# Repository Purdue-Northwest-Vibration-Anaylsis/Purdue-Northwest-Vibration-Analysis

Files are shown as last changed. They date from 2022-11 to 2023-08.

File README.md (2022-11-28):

# Purdue-Northwest-Vibration-Analysis
Vibration analysis senior design project for Purdue Northwest.

# Background
Household appliances breaking down is a costly issue for everyday consumers. 
There are typically two options when an appliance breaks down: reactive maintenance or buying a replacement, both of which are extremely costly. Proactive maintenance, as opposed to reactive maintenance, is identifying and fixing the issue before it results in a breakdown. Industries, such as the steel industry for example, have been investing in monitoring equipment on their machinery to identify and fix issues before they cause a total breakdown. Individual consumers do not yet have this luxury, so oftentimes their appliances completely break before they are aware of an issue.

# Objective
The open vibration analysis project seeks to prevent reactive maintenance of consumer appliances and instead allow the owners to perform proactive maintenance. Reactive maintenance, which is fixing the problem after it breaks down, is almost always more costly and time consuming than proactive maintenance, which is fixing a problem before it results in a complete breakdown. The objective of this project is to build a device that would be able to identify the problem before it results in a breakdown and alert the consumer to fix it. This would save the consumer money and reduce downtime. 

# Approach
The vibration analysis device would work by being attached to the consumer appliance.  It would use a combination of an accelerometer, to measure vibration, and a contact microphone, to measure sound. These measurements would be analyzed in a custom software that will be able to recognize any abnormalities in vibration or sound. That way, if the appliance begins to show signs of an imminent breakdown, the device will alert the user.

# Outcome
The anticipated outcome is a relatively small device, around 5”x5”, that can easily be attached to a consumer appliance, connected to a power supply, and easily configured with a user-friendly software. This software could connect to a phone and send notification alerts when the device senses abnormalities in the appliance. The device would ideally serve a wide range of consumers and work with most home appliances, such as washing/drying machines, refrigerators, AC units, and more.

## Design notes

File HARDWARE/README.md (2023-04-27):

# HARDWARE 
Sensors:

Accelerometer: ADXL345    
    
Microphone: SPH0645

Microprocessor/Bluetooth and WiFi Module:  ESP32-WROOM-32D

USB Bridge controller: CP2102 USB to UART

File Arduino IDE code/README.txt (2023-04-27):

These programs will allow you to test the functionality of the board, currently we have separate programs to test the components individually. 
In the future we will create programs that can test both components and perform computations such as FFT and filtering.

For the accelerometer testing code, you will need to install a few libraries on Arduino IDE.
First, you need to install the "Adafruit Unifier Sensor" library by Adafruit.
Next, install the "Adafruit ADXL345" library by Adafruit.
The ESP32 board can be on any version in the boards manager tab.
These are all you will need to test the accelerometer, but for more information consult this article: https://www.techcoil.com/blog/how-to-use-a-esp32-development-board-to-read-from-an-adxl345-accelerometer/

For the microphone testing code, you do not need to install any libraries.
The ESP32 board needs to be on version 1.0.3 in the boards manager tab for the code to work. 
This program has very basic filtering, but it still needs a lot of work.
This article contains more information: https://diyi0t.com/i2s-sound-tutorial-for-esp32/

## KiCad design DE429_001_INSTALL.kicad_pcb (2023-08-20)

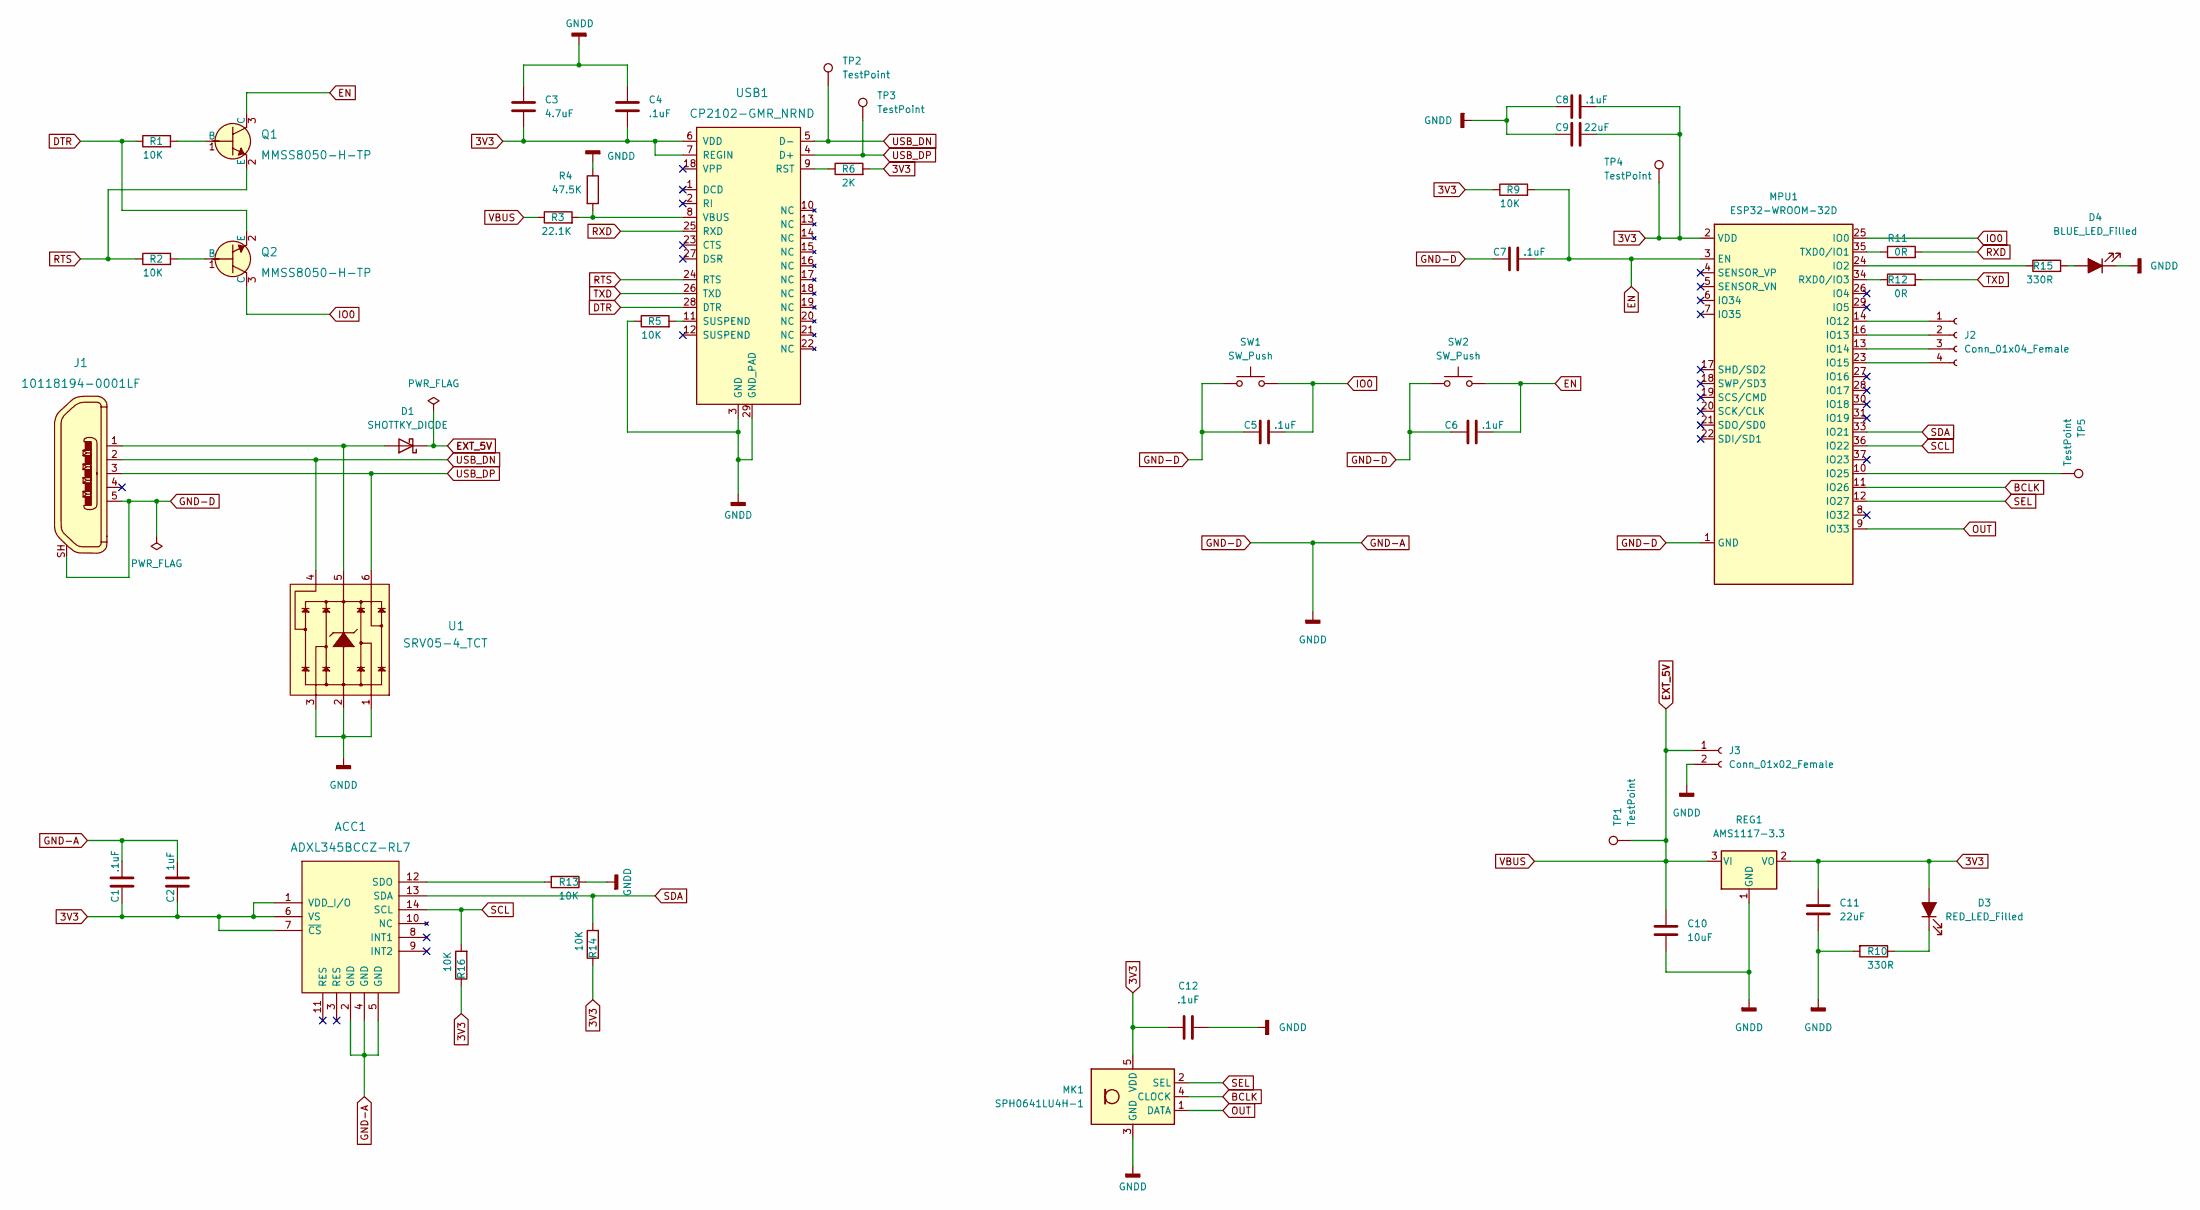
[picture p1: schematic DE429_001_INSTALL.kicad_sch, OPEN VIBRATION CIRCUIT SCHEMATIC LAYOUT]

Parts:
ACC1: ADXL345BCCZ-RL7; LGA-14_3x5mm_RevA; MPN ADXL345BCCZ-RL7; Digi-Key_PN ADXL345BCCZ-RL7CT-ND
C1, C4, C5, C6, C7, C8, C12: .1uF; C_0603_1608Metric
C2: 1uF; C_0603_1608Metric
C3: 4.7uF; C_0603_1608Metric
C9, C11: 22uF; C_0603_1608Metric
C10: 10uF; C_0603_1608Metric
D1: SHOTTKY_DIODE; D_SMA
D3: RED_LED_Filled; LED_0603_1608Metric
D4: BLUE_LED_Filled; LED_0603_1608Metric
J1: 10118194-0001LF; USB_Micro_B_Female_10118194-0001LF; MPN 10118194-0001LF; Digi-Key_PN 609-4618-1-ND
J2: Conn_01x04_Female; JST_XH_B4B-XH-AM_1x04_P2.50mm_Vertical
J3: Conn_01x02_Female; JST_XH_B2B-XH-AM_1x02_P2.50mm_Vertical
MK1: SPH0641LU4H-1; Knowles_LGA-5_3.5x2.65mm
MPU1: ESP32-WROOM-32D; ESP32-WROOM-32
Q1, Q2: MMSS8050-H-TP; SOT-23-3; MPN MMSS8050-H-TP; Digi-Key_PN MMSS8050-H-TPMSCT-ND
R1, R2, R5, R9, R13, R14, R16: 10K; R_0603_1608Metric
R3: 22.1K; R_0603_1608Metric
R4: 47.5K; R_0603_1608Metric
R6: 2K; R_0603_1608Metric
R10, R15: 330R; R_0603_1608Metric
R11, R12: 0R; R_0603_1608Metric
REG1: AMS1117-3.3; SOT-223-3_TabPin2
SW1, SW2: SW_Push; SW_SPST_TL3342
TP1, TP2, TP3, TP4, TP5: TestPoint; TestPoint_THTPad_D3.0mm_Drill1.5mm
U1: SRV05-4_TCT; SOT-23-6; MPN SRV05-4.TCT; Digi-Key_PN SRV05-4CT-ND
USB1: CP2102-GMR_NRND; VFQFN-28-1EP_5x5mm; MPN CP2102-GMR; Digi-Key_PN 336-1160-1-ND

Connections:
3V3: ACC1.1 (VDD_I/O), ACC1.6 (VS), ACC1.7 (~CS), C1.1, C2.1, C3.2, C4.2, C8.1, C9.1, C11.1, C12.1, D3.2 (A), MK1.5 (VDD), MPU1.2 (VDD), R6.2, R9.1, R14.1, R16.1, REG1.2 (VO), TP4.1, USB1.6 (VDD), USB1.7 (REGIN)
BCLK: MK1.4 (CLOCK), MPU1.11 (IO26)
DTR: Q2.2 (E), R1.1, USB1.28 (DTR)
EN: C6.2, C7.2, MPU1.3 (EN), Q1.3 (C), R9.2, SW2.2
EXT_5V: C10.1, D1.1 (K), J3.1, R3.1, REG1.3 (VI), TP1.1; also elsewhere on the board
GND-A: ACC1.2 (GND), ACC1.4 (GND), ACC1.5 (GND), C1.2, C2.2, C3.1, C4.1, C5.1, C6.1, C7.1, C8.2, C9.2, C10.2, C11.2, C12.2, D4.1 (K), J1.5, J1.SH, J3.2, MK1.3 (GND), MPU1.1 (GND), MPU1.15 (GND), MPU1.38 (GND), MPU1.39 (GND), R4.1, R5.1, R10.2, R13.1, REG1.1 (GND), SW1.1, SW2.1, U1.1, U1.2, U1.3, USB1.3 (GND), USB1.29 (GND_PAD)
IO0: C5.2, MPU1.25 (IO0), Q2.3 (C), SW1.2
unnamed: ACC1.12 (SDO), R13.2
unnamed 8: D1.2 (A), J1.1, U1.5; also elsewhere on the board
unnamed: D3.1 (K), R10.1
unnamed: D4.2 (A), R15.2
unnamed: J2.1, MPU1.14 (IO12)
unnamed: J2.2, MPU1.16 (IO13)
unnamed: J2.3, MPU1.13 (IO14)
unnamed: J2.4, MPU1.23 (IO15)
unnamed: MPU1.10 (IO25), TP5.1
unnamed: MPU1.24 (IO2), R15.1
unnamed: MPU1.34 (RXD0/IO3), R12.1
unnamed: MPU1.35 (TXD0/IO1), R11.1
unnamed: Q1.1 (B), R1.2
unnamed: Q2.1 (B), R2.2
unnamed: R3.2, R4.2, USB1.8 (VBUS)
unnamed: R5.2, USB1.11 (SUSPEND)
unnamed: R6.1, USB1.9 (RST)
OUT: MK1.1 (DATA), MPU1.9 (IO33)
RTS: Q1.2 (E), R2.1, USB1.24 (RTS)
RXD: R11.2, USB1.25 (RXD)
SCL: ACC1.14 (SCL), MPU1.36 (IO22), R16.2
SDA: ACC1.13 (SDA), MPU1.33 (IO21), R14.2
SEL: MK1.2 (SEL), MPU1.12 (IO27)
TXD: R12.2, USB1.26 (TXD)
USB_DN: J1.2, TP2.1, U1.4, USB1.5 (D-)
USB_DP: J1.3, TP3.1, U1.6, USB1.4 (D+)

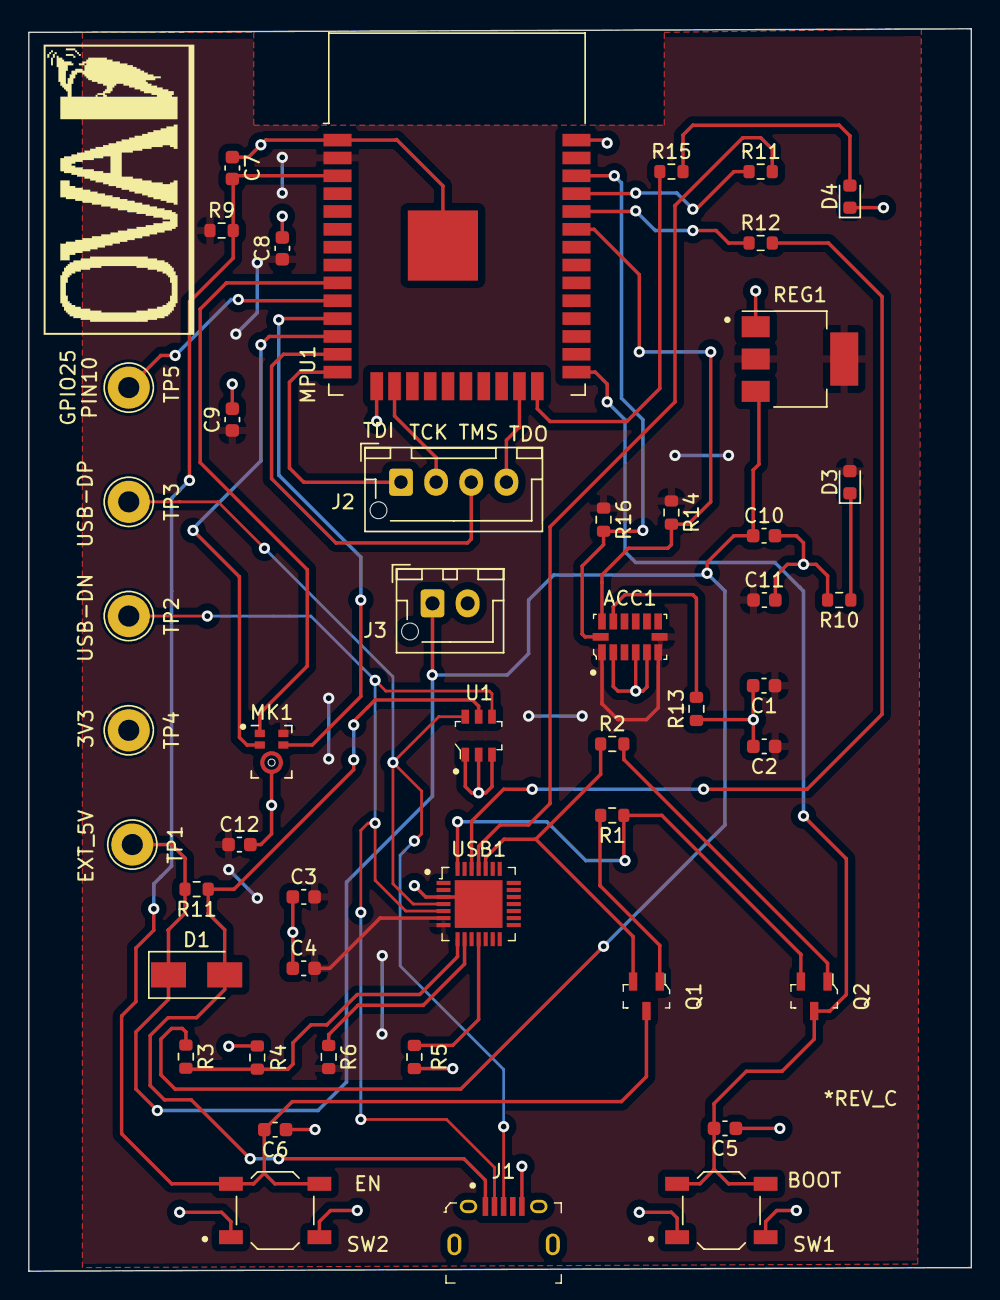
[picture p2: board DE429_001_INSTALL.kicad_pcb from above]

Board: 2 copper layers, 67.1 x 88.4 mm, 48 parts (0 on the bottom side), 33 nets.

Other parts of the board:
R11#2: 2K; R_0603_1608Metric

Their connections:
EXT_5V: R11#2.2; also elsewhere on the board
unnamed 8: R11#2.1; also elsewhere on the board

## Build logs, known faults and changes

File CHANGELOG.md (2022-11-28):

# Changelog
All notable changes to this project will be documented in this file.

The format is based on [Keep a Changelog](https://keepachangelog.com/en/1.0.0/)
and this project adheres to [Semantic Versioning](https://semver.org/spec/v2.0.0.html).

## [Unreleased]

### Added

# 11/27/2022 
New updates to the PCB Schematics were done.

### Changed

# 11/27/2022
Changed the mircophone to a Ziltek ZTS6117 mircophone in order to have all components printed on the PCB.

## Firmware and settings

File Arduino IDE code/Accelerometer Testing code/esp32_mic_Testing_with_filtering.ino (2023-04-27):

#include "driver/i2s.h"


const i2s_port_t I2S_PORT = I2S_NUM_0;

void setup() {
  Serial.begin(115200);
  esp_err_t err;

  // The I2S config as per the example
  const i2s_config_t i2s_config = {
      .mode = i2s_mode_t(I2S_MODE_MASTER | I2S_MODE_RX), // Receive, not transfer
      .sample_rate = 16000,                         // 16KHz
      .bits_per_sample = I2S_BITS_PER_SAMPLE_32BIT, // could only get it to work with 32bits
      .channel_format = I2S_CHANNEL_FMT_ONLY_RIGHT, // use right channel
      .communication_format = i2s_comm_format_t(I2S_COMM_FORMAT_I2S | I2S_COMM_FORMAT_I2S_MSB),
      .intr_alloc_flags = ESP_INTR_FLAG_LEVEL1,     // Interrupt level 1
      .dma_buf_count = 4,                           // number of buffers
      .dma_buf_len = 8                              // 8 samples per buffer (minimum)
  };

  // The pin config as per the setup
  const i2s_pin_config_t pin_config = {
      .bck_io_num = 26,   // Serial Clock (SCK)
      .ws_io_num = 27,    // Word Select (WS)
      .data_out_num =  I2S_PIN_NO_CHANGE, // not used (only for speakers)
      .data_in_num = 33,   // Serial Data (SD)
  };

  // Configuring the I2S driver and pins.
  // This function must be called before any I2S driver read/write operations.
  err = i2s_driver_install(I2S_PORT, &i2s_config, 0, NULL);
  if (err != ESP_OK) {
    Serial.printf("Failed installing driver: %d\n", err);
    while (true);
  }
  err = i2s_set_pin(I2S_PORT, &pin_config);
  if (err != ESP_OK) {
    Serial.printf("Failed setting pin: %d\n", err);
    while (true);
  }
  Serial.println("I2S driver installed.");
}

void loop() {
  // Read a single sample and log it for the Serial Plotter.
  int32_t sample = 0;
  int bytes_read = i2s_pop_sample(I2S_PORT, (char *)&sample, portMAX_DELAY); // no timeout
  if (bytes_read > 0) {
    if (abs(sample) < 1970000000) 
    {
    sample = 0;
    }
    else
    {
    sample=sample*.000001;
    }
    //if (sample > 1900000000)
    //{
    Serial.println(sample);
    //}
  }


}
